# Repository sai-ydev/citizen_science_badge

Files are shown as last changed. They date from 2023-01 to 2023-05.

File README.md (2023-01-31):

# Citizen Science Badge

This repository contains all the hardware files, firmware for the Citizen Science Badge. A detailed write-up of this badge is available from [here](https://www.hackster.io/yamanoorsai/citizen-science-badge-c66165).

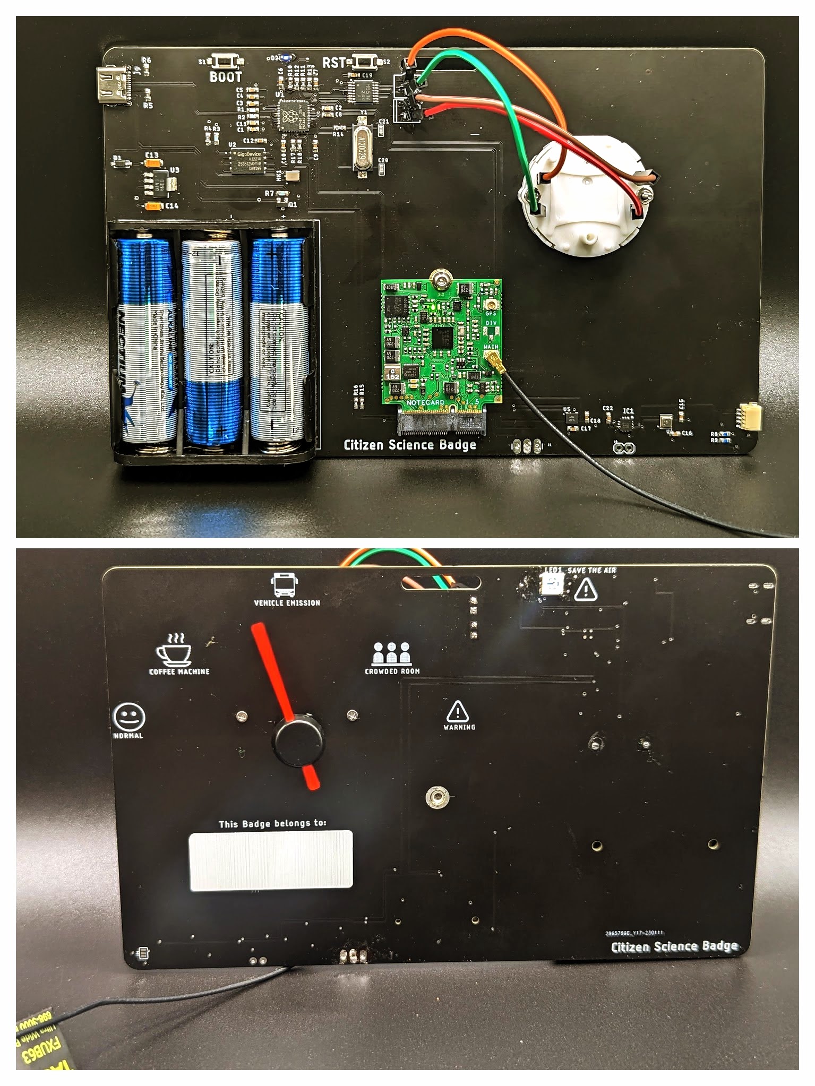
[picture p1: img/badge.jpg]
Citizen Science Badge


The badge consists of the following components:

* Raspberry Pi RP2040 microcontroller with 64MB flash.
* Invensense ICS-41350 MEMS Microphone. The audio captured from the microphone is used to detect sound using Edge Impulse
* Blues Wireless cellular module is used to upload data points to the cloud as well as receive "Save The Air" alerts from the cloud.
* Automotive Gauge Stepper Motor (x27.168) - Used to indicate measured air quality index.
* Bosch BMI270 IMU to detect motion
* DA7280 for haptic feedback
* BME688 air quality sensor to calculate air quality index as well as detect odors
* JST/ Qwiic sensor port for connecting external sensors.
* 3 x AA battery pack
* USB C port for programming.

## Firmware

Currently, the proof of concept has been implemented using Arduino. I plan to implement the code using the RP2040's C SDK. 

I have identified the following items as technical debt for this project.

* Implementing LED behavior for "Spare the Air" alerts
* The PCB design needs to be revised for low power operation
* The code needs to be re-written using the Pico C SDK
* Power profiling the badge

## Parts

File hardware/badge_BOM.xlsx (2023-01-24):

Part | Value | Description | MPN | Remarks
BT1 | BC3AAPC | BC3AAPC | BC3AAPC | Do not Fit
C1, C2, C5, C6, C7, C8, C9, C10, C11, C12, C15, C16, C17, C18, C22 | 0.1uF | CAP CER 0.1UF 25V X7R 0603 | C0603C104K3RAC7867
C3, C4, C19 | 1.0uF | CAP CER 1UF 50V X5R 0603 | GRT188R61H105KE13D
C13 | 68uF | CAP TANT 68UF 20% 6.3V 1206 | T491A686M006AT
C14 | 33uF | CAP TANT 33UF 10% 6.3V 1206 | TAJA336K006RNJ
C20, C21 | 27pf | CAP CER 27PF 50V C0G 0603 | CGA3E2C0G1H270J080AA
D1 | 600 mV @ 200 mA | DIODE SCHOTTKY 30V 350MA SOD123 | SD103BWHE3-TP
D2 | BLUE | LED BLUE 0603 SMD | 5973604507F
IC1 | DA7280-00FVC | LRA/ERM HAPTIC DRIVER WLCSP15 | DA7280-00FVC
J1 |  | CONN_03LONGPADS | DNF
J3 |  | CONN_022.54MM_SCREWTERM | DNF
J4 |  | CONN_022.54MM_SCREWTERM | DNF
J5 |  | CONN HEADER SMD R/A 4POS 1MM | SM04B-SRSS-TB(LF)(SN)
J6 |  | CONN_02 | DNF
J7 | MDT420E01001 | CONN M.2 FMALE 67POS 0.020 GOLD | MDT420E01001
J9 | DX07S016JA1R1500 | CONN RCP USB2.0 TYP C 24P SMD RA | DX07S016JA1R1500
JP1 | JUMPER-SMT_3_NO_SILK | JUMPER-SMT_3_NO_SILK | DNF
LED1 | RGBLED5050 | RGB LED | DNF
MK1 | ICS-41350 | MICROPHONE MEMS DIGITAL PDM OMNI | ICS-41350
Q1 | 2.5A/30V/105mÎ© | MOSFET P-CH 30V 2.5A SOT-23 | DMG2307L-7
R1, R2 | 27 | RES 27 OHM 1% 1/10W 0603 | MCT06030C2709FP500
R3, R7 | 10k | RES 10K OHM 1% 1/10W 0603 | MCT06030C1002FPW00
R4, R11, R12, R13, R14 | 1k | RES 1K OHM 1% 1/8W 0603 | RNCP0603FTD1K00
R5, R6 | 5.1k | RES 5.1K OHM 5% 1/10W 0603 | RMCF0603JT5K10
R8, R9 | 4.7k | RES 4.7K OHM 0.5% 1/10W 0603 | MCT0603MD4701DP500
R10 | 330 | RES 330 OHM 5% 1/10W 0603 | RMCF0603JT330R
R15, R16, R17, R18 | 100 | RES 100 OHMS 0.1% 0.15W 0603 | RQ73C1J100RBTD
S1, S2 | MOMENTARY-SWITCH-SPST-SMD-6.0X3.5MM | TACT 6.0 X 3.5, 4.3 MM H, 130GF, | PTS636 SL43 SMTR LFS
U$1 | TC78H651AFNG | BRUSHED DC MOTOR DRIVER, DUAL-CH | TC78H651AFNG,EL
U1 | RP2040 | RP2040 | SC0914(7) (RP2040)
U2 | W25Q512JVEIM | W25Q512JVEIM | GD25S512MDYIGR
U3 | LP3961EMP-3.3 | IC REG LIN 3.3V 800MA SOT223-5 | LP3961EMP-3.3/NOPB
U4 | BME688 | SENSOR RH PRESSURE TEMP VOC | BME688
U5 | BMI270 | IMU ACCEL/GYRO I2C/SPI 14LGA | BMI270
Y1 | ABLS-12.000MHZ-B4-T | CRYSTAL 12.0000MHZ 18PF SMD | ABLS-12.000MHZ-B4-T

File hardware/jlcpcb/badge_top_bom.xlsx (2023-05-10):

Comment | Designator | Footprint | LCSC Part #
0.1uF | C1 C2 C5 C6 C7 C8 C9 C10 C11 C12 C15 C16 C17 C18 C22 | 603 | C141382
1.0uF | C3 C4 C19 | 603 | C2857982
30V 350mA SOD123 | D1 | SOD123 | C5204743
1k | R11 R12 R13 R14 | 603 | C3017736
2.5A/30V/105mÎ© | Q1 | SOT23-3 | C5182052
4.7k | R8 R9 | 603 | C2904521
5.1k | R5 R6 | 603 | C269716
10k | R3 R7 | 603 | C3017715
27 | R1 R2 | 603 | C176155
27pf | C20 C21 | C0603 | C913896
33uF | C14 | CAPMP3216X180N | C1953983
68uF | C13 | CAPMP3216X180N | C1952895
100 | R15 R16 R17 R18 | 603 | C881316
330 | R10 | 603 | C881395
ABLS-12.000MHZ-B4-T | Y1 | XTAL_ABLS-12.000MHZ-B4-T | ABLS-12.000MHZ-B4-T
BLUE | D2 | LED-0603 | C84266
BME688 | U4 | IC_BME688 | C3664478
BMI270 | U5 | XDCR_BMI270 | C2836813
DA7280-00FVC | IC1 | QFN65P300X300X84-12N | C2155359
DX07S016JA1R1500 | J9 | JAE_DX07S016JA1R1500 | DX07S016JA1R1500
ICS-41350 | MK1 | MIC_ICS-41350 | C2895290
LP3961EMP-3.3 | U3 | SOT150P696X180-5N | C3746120
MDT420E01001NOTECARD | J7 | NOTECARD | MDT420E01001
CONN HEADER SMD R/A 4POS 1MM | J5 |  | C160404
MOMENTARY-SWITCH-SPST-SMD-6.0X3.5MM | S1 S2 | TACTILE_SWITCH_SMD_6.0X3.5MM | C2886923
RP2040 | U1 | QFN40P700X700X90-57N | C2040
TC78H651AFNG | U$1 | P-TSSOP16-0505-0.65-001 | TC78H651AFNG
W25Q512JVEIM | U2 | SON127P600X800X80-9N | C2886434

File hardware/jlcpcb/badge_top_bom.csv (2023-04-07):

Comment | Designator | Footprint | LCSC Part #
0.1uF | D1 J5 C1 C2 C5 C6 C7 C8 C9 C10 C11 C12 C15 C16 C17 C18 C22 | 0603
1.0uF | C3 C4 C19 | 0603
1k | R11 R12 R13 R14 | 0603
2.5A/30V/105mΩ | Q1 | SOT23-3
4.7k | R8 R9 | 0603
5.1k | R5 R6 | 0603
10k | R3 R7 | 0603
27 | R1 R2 | 0603
27pf | C20 C21 | C0603
33uF | C14 | CAPMP3216X180N
68uF | C13 | CAPMP3216X180N
100 | R15 R16 R17 R18 | 0603
330 | R10 | 0603
ABLS-12.000MHZ-B4-T | Y1 | XTAL_ABLS-12.000MHZ-B4-T
BLUE | D2 | LED-0603
BME688 | U4 | IC_BME688
BMI270 | U5 | XDCR_BMI270
DA7280-00FVC | IC1 | QFN65P300X300X84-12N
DX07S016JA1R1500 | J9 | JAE_DX07S016JA1R1500
ICS-41350 | MK1 | MIC_ICS-41350
LP3961EMP-3.3 | U3 | SOT150P696X180-5N
MDT420E01001NOTECARD | J7 | NOTECARD
MOMENTARY-SWITCH-SPST-SMD-6.0X3.5MM | S1 S2 | TACTILE_SWITCH_SMD_6.0X3.5MM
RP2040 | U1 | QFN40P700X700X90-57N
TC78H651AFNG | U$1 | P-TSSOP16-0505-0.65-001
W25Q512JVEIM | U2 | SON127P600X800X80-9N

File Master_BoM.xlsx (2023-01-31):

Item | Manufacturer / Vendor | Price | Remarks
Fully Assembled PCB | PCBWay | 103.6 | PCB BoM in Github contains more detailed information
Automotive Stepper | Adafruit | 9.95
3 x AA Batteries | Amazon | 3
Notecard cellular module | Blues Wireless | 64.9
Cellular module antenna | Taoglas | 11.91
 | Total | 193.36

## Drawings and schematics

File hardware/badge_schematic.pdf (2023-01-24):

A

A

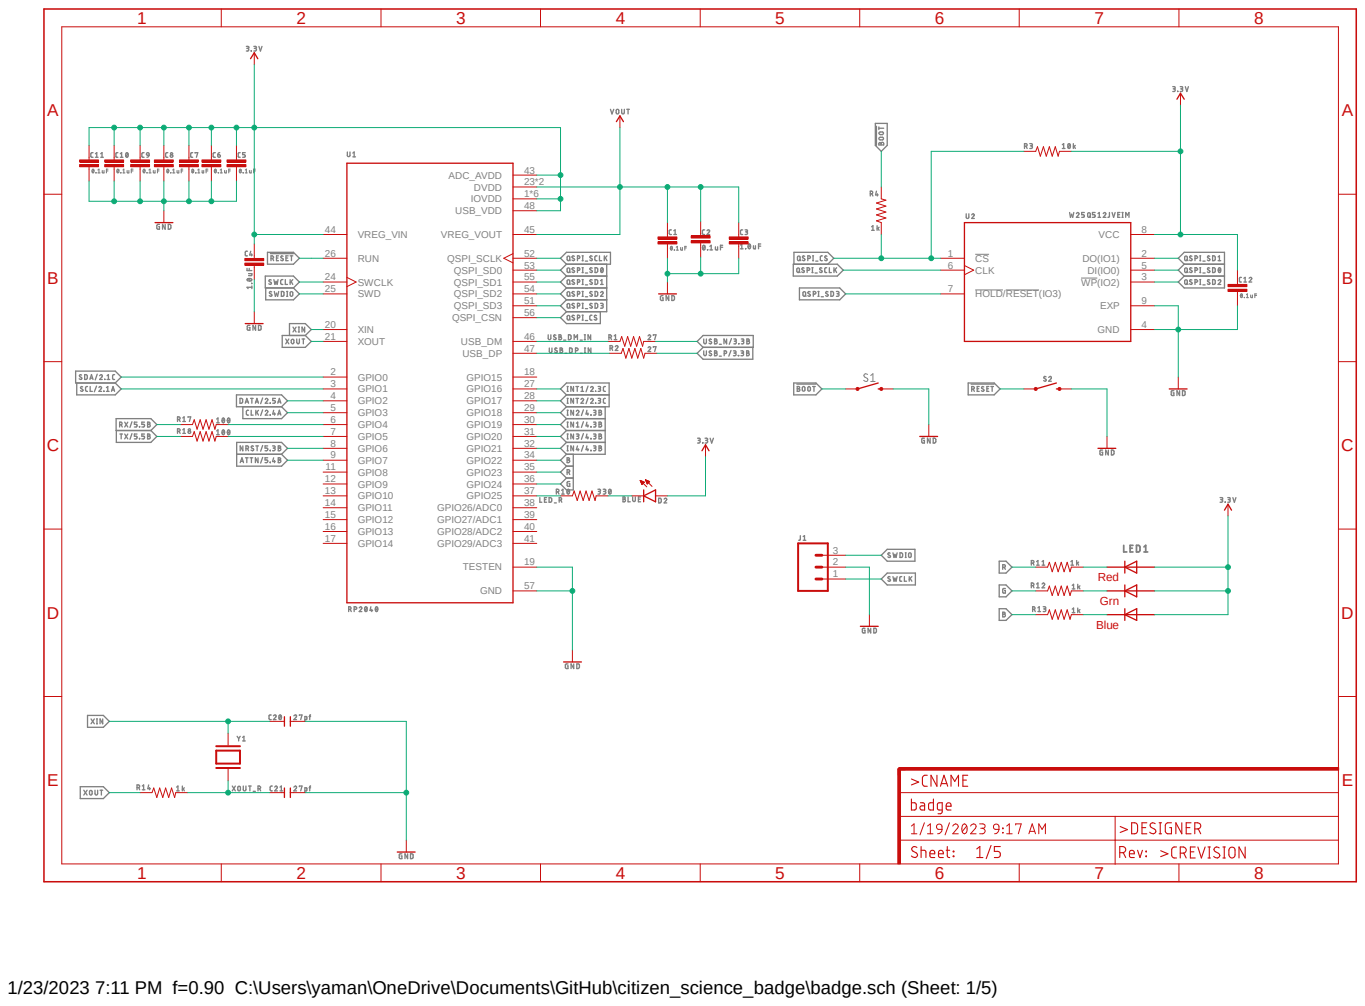
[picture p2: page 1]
GPIO0 2; GPIO1 3; GPIO2 4; GPIO3 5; GPIO4 6; GPIO5 7; GPIO6 8; GPIO7 9; GPIO8 11; GPIO9 12; GPIO10 13; GPIO11 14; GPIO12 15; GPIO13 16; GPIO14 17; GPIO15; 18 GPIO16; 27 GPIO17; 28 GPIO18; 29 GPIO19; 30 GPIO20; 31 GPIO21; 32 GPIO22; 34 GPIO23; 35 GPIO24; 36 GPIO25; 37 GPIO26/ADC0; 38 GPIO27/ADC1; 39 GPIO28/ADC2; 40 GPIO29/ADC3; 41 QSPI_SD3; 51 QSPI_SCLK; 52 QSPI_SD0; 53 QSPI_SD2; 54 QSPI_SD1; 55 QSPI_CSN; 56 XIN 20; XOUT 21; SWCLK 24; SWD 25; RUN 26; TESTEN; 19 USB_DP; 47 USB_DM; 46 VREG_VOUT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

1/23/2023 7:11 PM f=0.90 C:\Users\yaman\OneDrive\Documents\GitHub\citizen_science_badge\badge.sch (Sheet: 1/5)

A

A

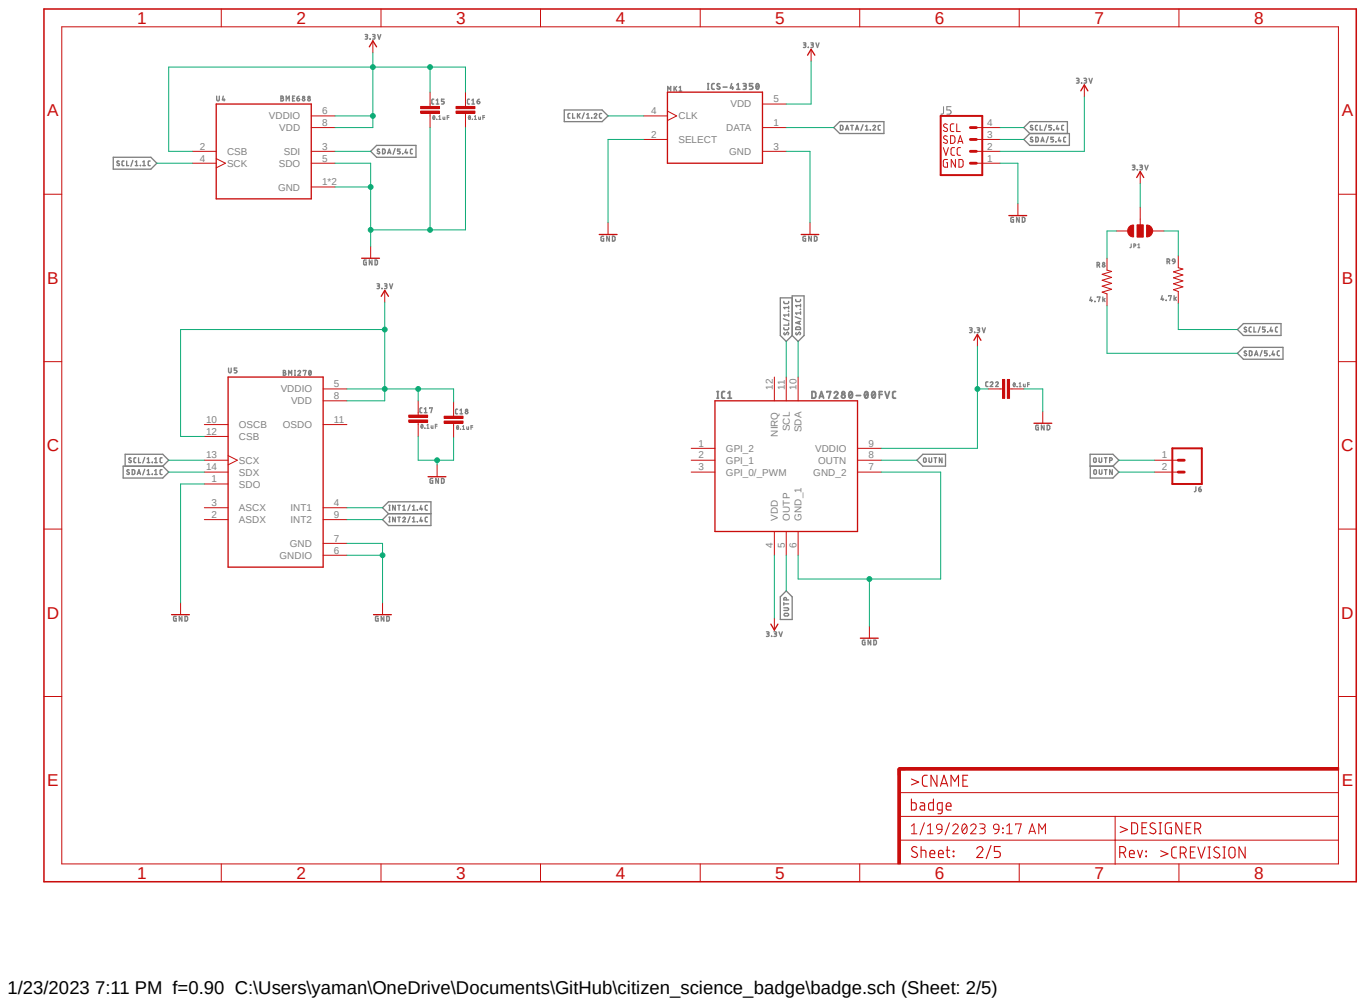
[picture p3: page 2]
CSB 2; SDI; 3 SCK 4; SDO; 5 VDDIO; 6 GND; 1*2 VDD; SDO 1; ASDX 2; ASCX 3; INT1; 4 VDDIO; 5 GNDIO; 7 VDD; INT2; 9 OSDO; 11 CSB 12; OSCB 10; SCX 13; SDX 14; VDD; 5 DATA; 1 GND; 3 CLK 4; SELECT 2; 4 GPI_2 1; GPI_1 2; GPI_0/_PWM 3; 4 OUTP; 5 GND_1

6 VDDIO 9 OUTN 8 GND_2 7 NIRQ 12 SCL 11 SDA 10

1/23/2023 7:11 PM f=0.90 C:\Users\yaman\OneDrive\Documents\GitHub\citizen_science_badge\badge.sch (Sheet: 2/5)

A

1 | 2 | 3 | 4 | 5 | 6 | 7 | 8

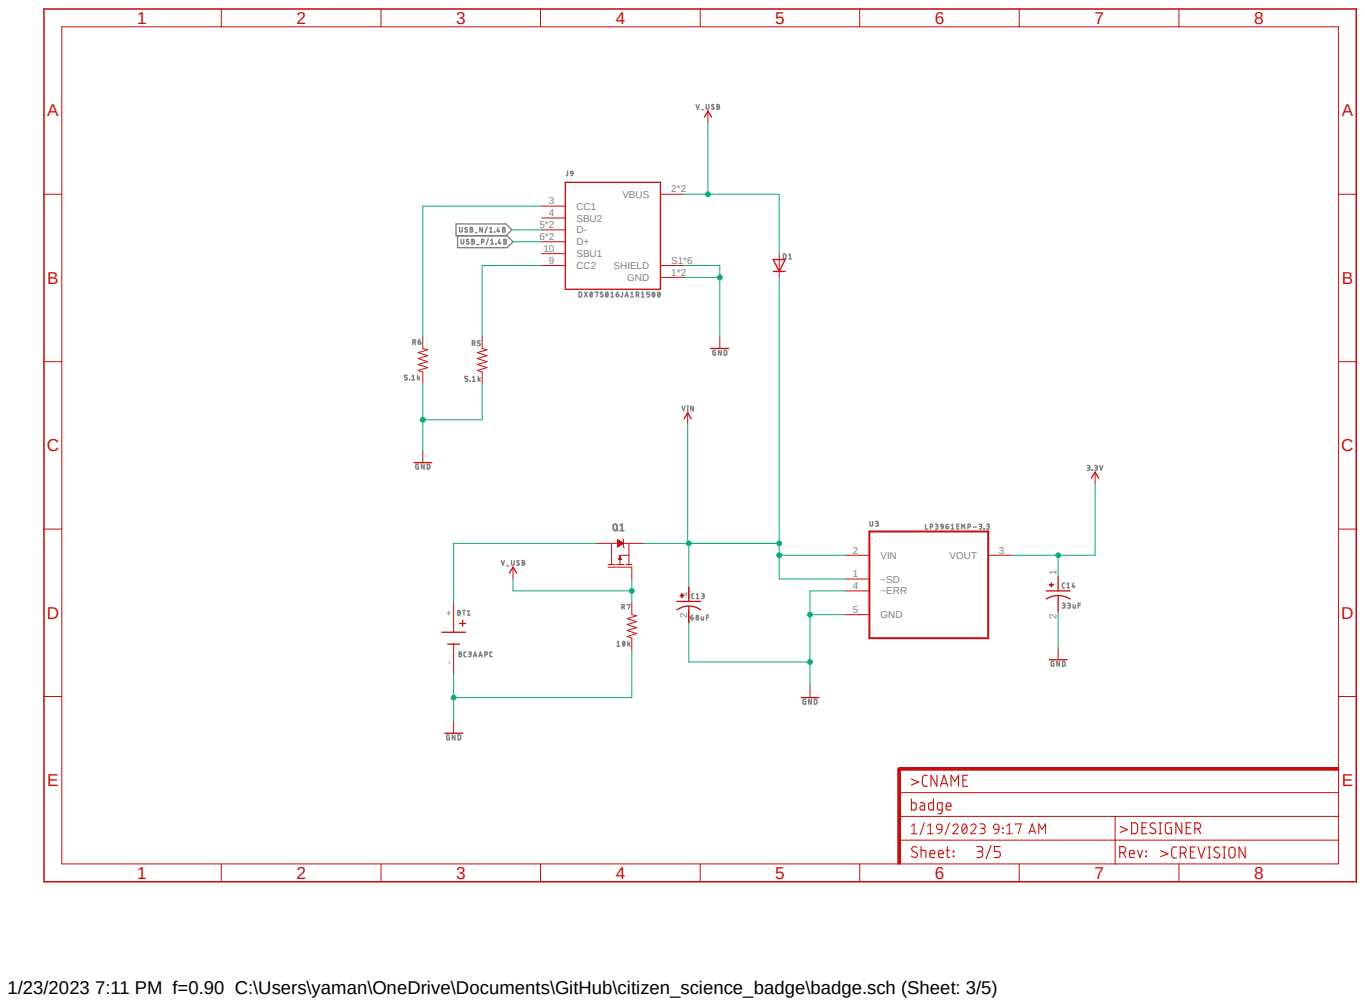
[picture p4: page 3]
VIN 2; ~ERR 4; GND 5; VOUT; GND; 1*2 VBUS; SBU2 4; SBU1 10; SHIELD

1/23/2023 7:11 PM f=0.90 C:\Users\yaman\OneDrive\Documents\GitHub\citizen_science_badge\badge.sch (Sheet: 3/5)

A

A

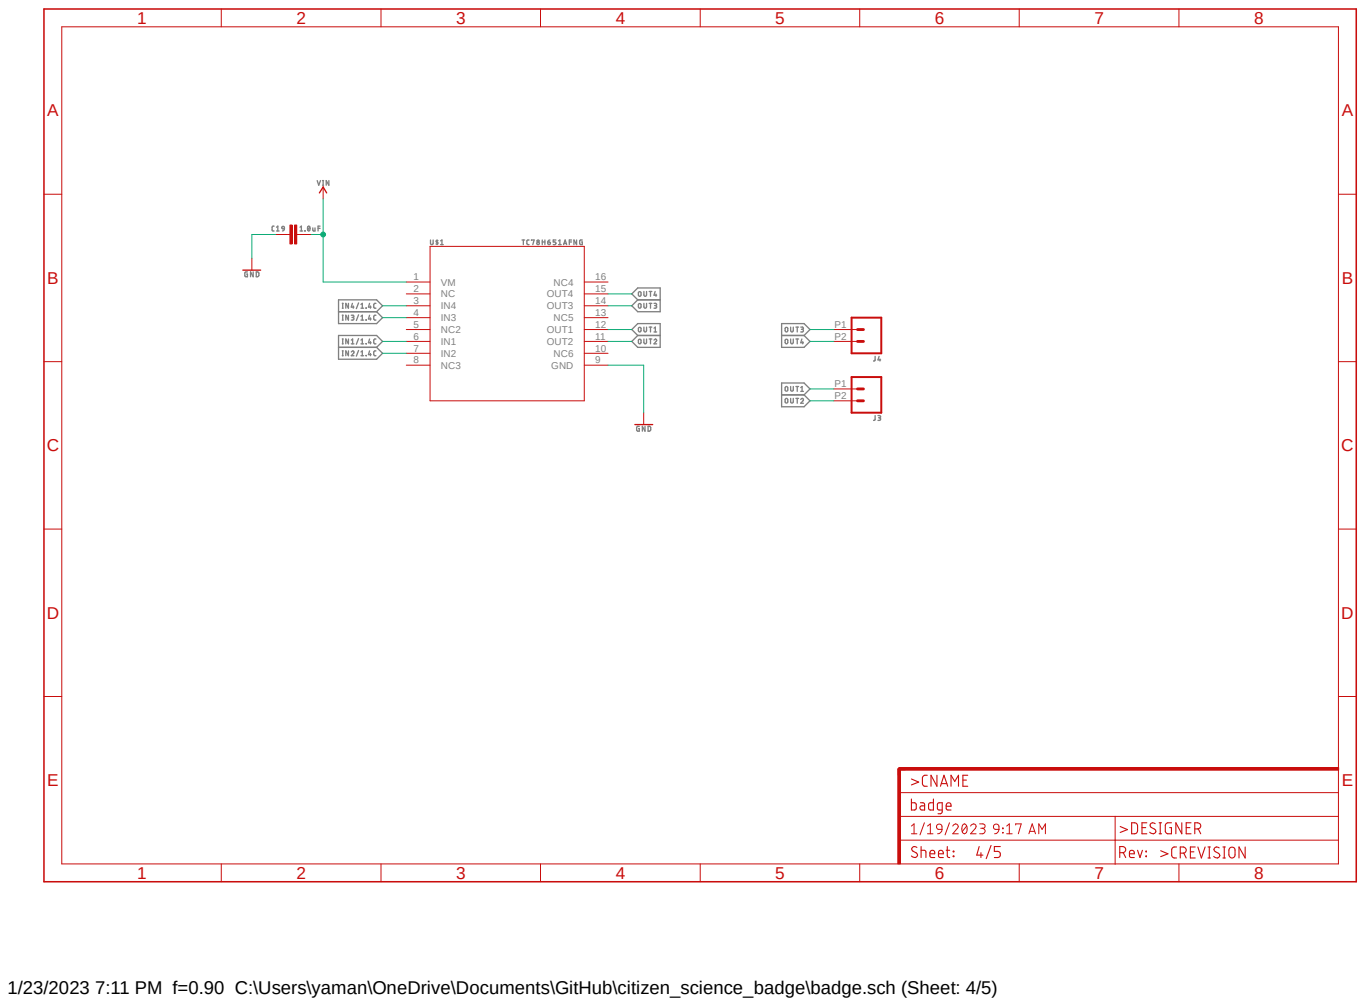
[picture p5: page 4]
GND; 10 OUT2; 11 OUT1; 13 OUT3; 14 OUT4

1/23/2023 7:11 PM f=0.90 C:\Users\yaman\OneDrive\Documents\GitHub\citizen_science_badge\badge.sch (Sheet: 4/5)

A

A

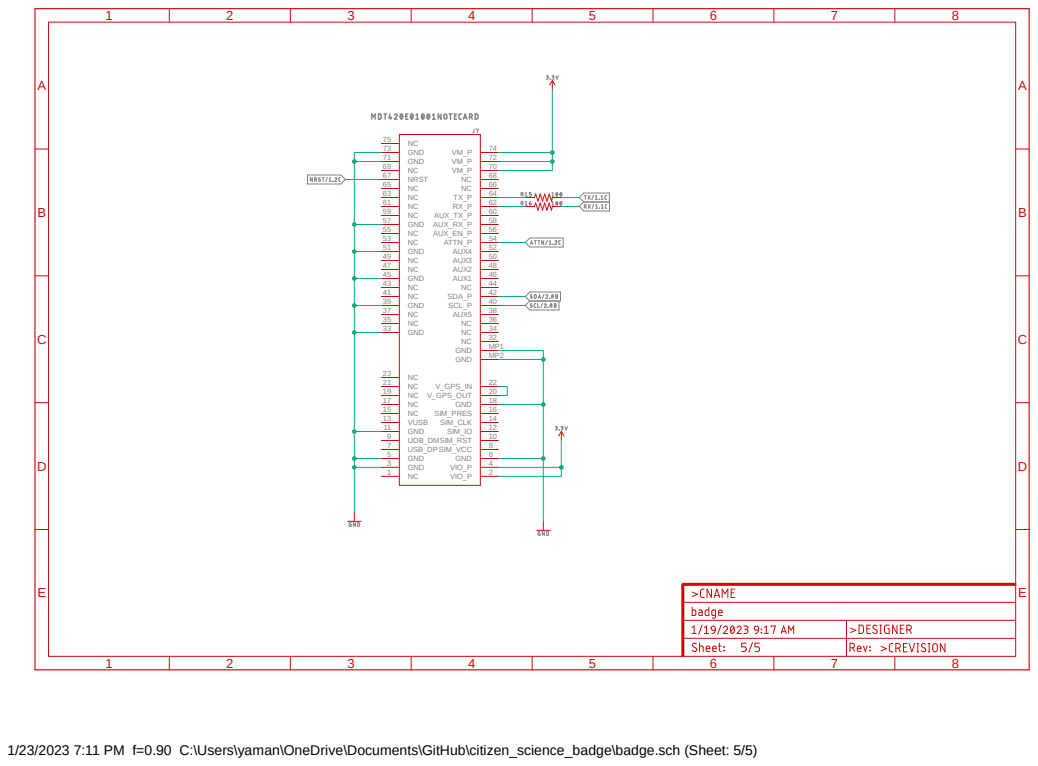
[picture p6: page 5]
VIO_P; 2 GND 3; 4 GND 5; GND; 6 USB_DP 7; SIM_VCC; 8 UDB_DM 9; SIM_RST; 10 GND 11; SIM_IO; 12 VUSB 13; SIM_CLK; SIM_PRES; V_GPS_OUT; V_GPS_IN; 32 GND 33; AUX5; 38 GND 39; SCL_P; SDA_P; 44 GND 45; AUX1; AUX2; AUX3; 50 GND 51; AUX4; ATTN_P; AUX_EN_P; 56 GND 57; AUX_RX_P; AUX_TX_P; 66 NRST 67; 70 GND 71; 72 GND 73; MP1 GND

1/23/2023 7:11 PM f=0.90 C:\Users\yaman\OneDrive\Documents\GitHub\citizen_science_badge\badge.sch (Sheet: 5/5)

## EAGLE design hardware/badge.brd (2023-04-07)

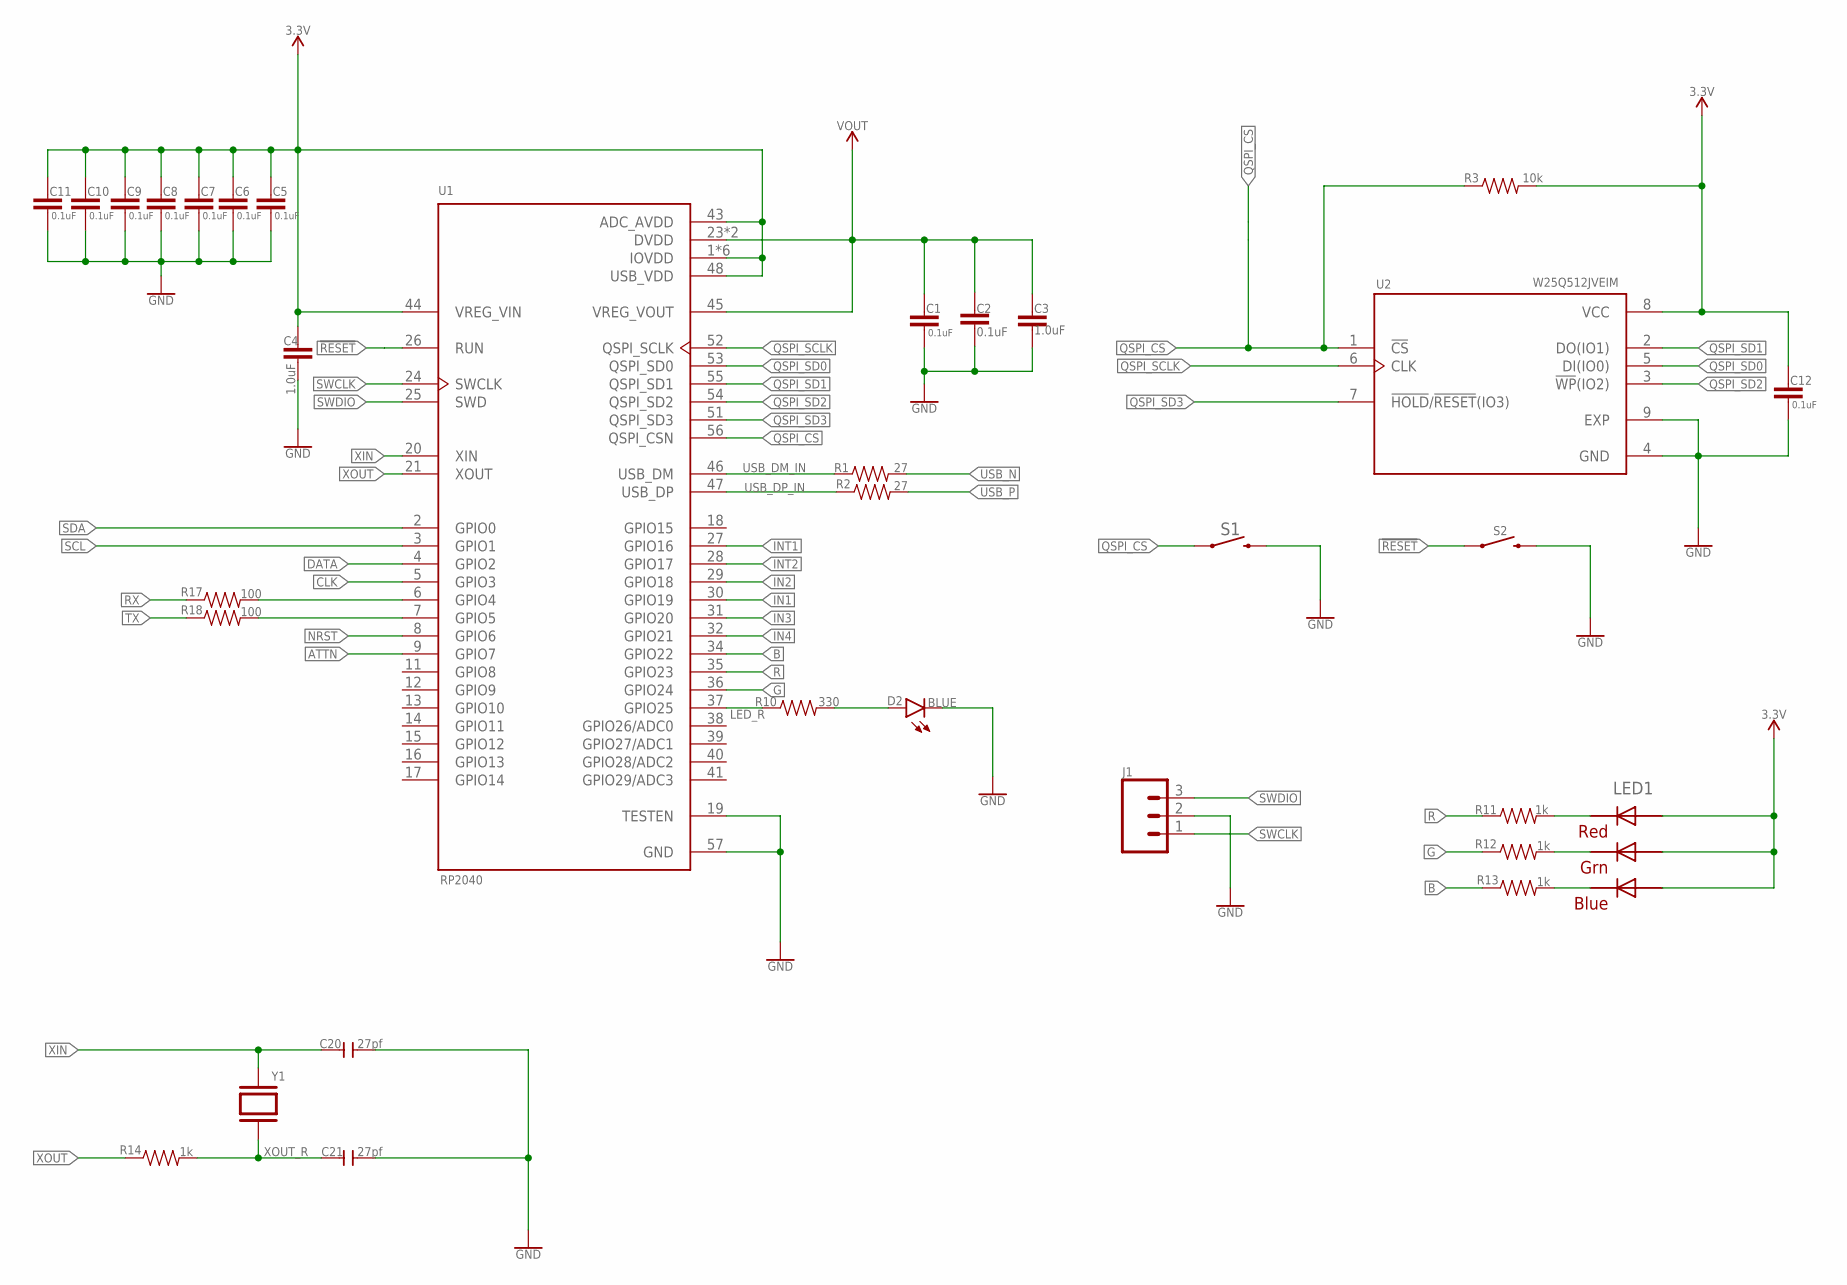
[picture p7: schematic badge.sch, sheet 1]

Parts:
C1, C2, C5, C6, C7, C8, C9, C10, C11, C12: 0.1uF; 0603
C3, C4: 1.0uF; 0603
C20, C21: 27pf; C0603
D2: BLUE; LED-0603
J1: CONN_03LONGPADS; 1X03_LONGPADS
LED1: RGBLED5050
R1, R2: 27; 0603
R3: 10k; 0603
R10: 330; 0603
R11, R12, R13, R14: 1k; 0603
R17, R18: 100; 0603
S1, S2: MOMENTARY-SWITCH-SPST-SMD-6.0X3.5MM; TACTILE_SWITCH_SMD_6.0X3.5MM
U1: RP2040; QFN40P700X700X90-57N
U2: W25Q512JVEIM; SON127P600X800X80-9N
Y1: ABLS-12.000MHZ-B4-T; XTAL_ABLS-12.000MHZ-B4-T

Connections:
3.3V: C4.1, C5.1, C6.1, C7.1, C8.1, C9.1, C10.1, C11.1, C12.1, LED1.1 (GREEN_A), LED1.2 (RED_A), LED1.3 (BLUE_A), R3.2, U1.1 (IOVDD), U1.10 (IOVDD), U1.22 (IOVDD), U1.33 (IOVDD), U1.42 (IOVDD), U1.43 (ADC_AVDD), U1.44 (VREG_VIN), U1.48 (USB_VDD), U1.49 (IOVDD), U2.8 (VCC); also elsewhere on the board
!RESET: S2.1, U1.26 (RUN)
ATTN: U1.9 (GPIO7); also elsewhere on the board
B: R13.1, U1.34 (GPIO22)
CLK: U1.5 (GPIO3); also elsewhere on the board
DATA: U1.4 (GPIO2); also elsewhere on the board
G: R12.1, U1.36 (GPIO24)
GND: C1.2, C2.2, C3.2, C4.2, C5.2, C6.2, C7.2, C8.2, C9.2, C10.2, C11.2, C12.2, C20.2, C21.2, D2.C, J1.2, S1.2, S2.2, U1.19 (TESTEN), U1.57 (GND), U2.4 (GND), U2.9 (EXP); also elsewhere on the board
IN1: U1.30 (GPIO19); also elsewhere on the board
IN2: U1.29 (GPIO18); also elsewhere on the board
IN3: U1.31 (GPIO20); also elsewhere on the board
IN4: U1.32 (GPIO21); also elsewhere on the board
INT1: U1.27 (GPIO16); also elsewhere on the board
INT2: U1.28 (GPIO17); also elsewhere on the board
LED_R: R10.1, U1.37 (GPIO25)
unnamed: D2.A, R10.2
unnamed: LED1.5 (RED_C), R11.2
unnamed: LED1.6 (GREEN_C), R12.2
unnamed: LED1.4 (BLUE_C), R13.2
unnamed: R17.2, U1.6 (GPIO4)
unnamed: R18.2, U1.7 (GPIO5)
NRST: U1.8 (GPIO6); also elsewhere on the board
QSPI_CS: R3.1, S1.1, U1.56 (QSPI_CSN), U2.1 (!CS)
QSPI_SCLK: U1.52 (QSPI_SCLK), U2.6 (CLK)
QSPI_SD0: U1.53 (QSPI_SD0), U2.5 (DI(IO0))
QSPI_SD1: U1.55 (QSPI_SD1), U2.2 (DO(IO1))
QSPI_SD2: U1.54 (QSPI_SD2), U2.3 (!WP!(IO2))
QSPI_SD3: U1.51 (QSPI_SD3), U2.7 (!HOLD!/!RESET!(IO3))
R: R11.1, U1.35 (GPIO23)
RX: R17.1; also elsewhere on the board
SCL: U1.3 (GPIO1); also elsewhere on the board
SDA: U1.2 (GPIO0); also elsewhere on the board
SWCLK: J1.1, U1.24 (SWCLK)
SWDIO: J1.3, U1.25 (SWD)
TX: R18.1; also elsewhere on the board
USB_DM_IN: R1.1, U1.46 (USB_DM)
USB_DP_IN: R2.1, U1.47 (USB_DP)
USB_N: R1.2; also elsewhere on the board
USB_P: R2.2; also elsewhere on the board
VOUT: C1.1, C2.1, C3.1, U1.23 (DVDD), U1.45 (VREG_VOUT), U1.50 (DVDD)
XIN: C20.1, U1.20 (XIN), Y1.2
XOUT: R14.1, U1.21 (XOUT)
XOUT_R: C21.1, R14.2, Y1.1

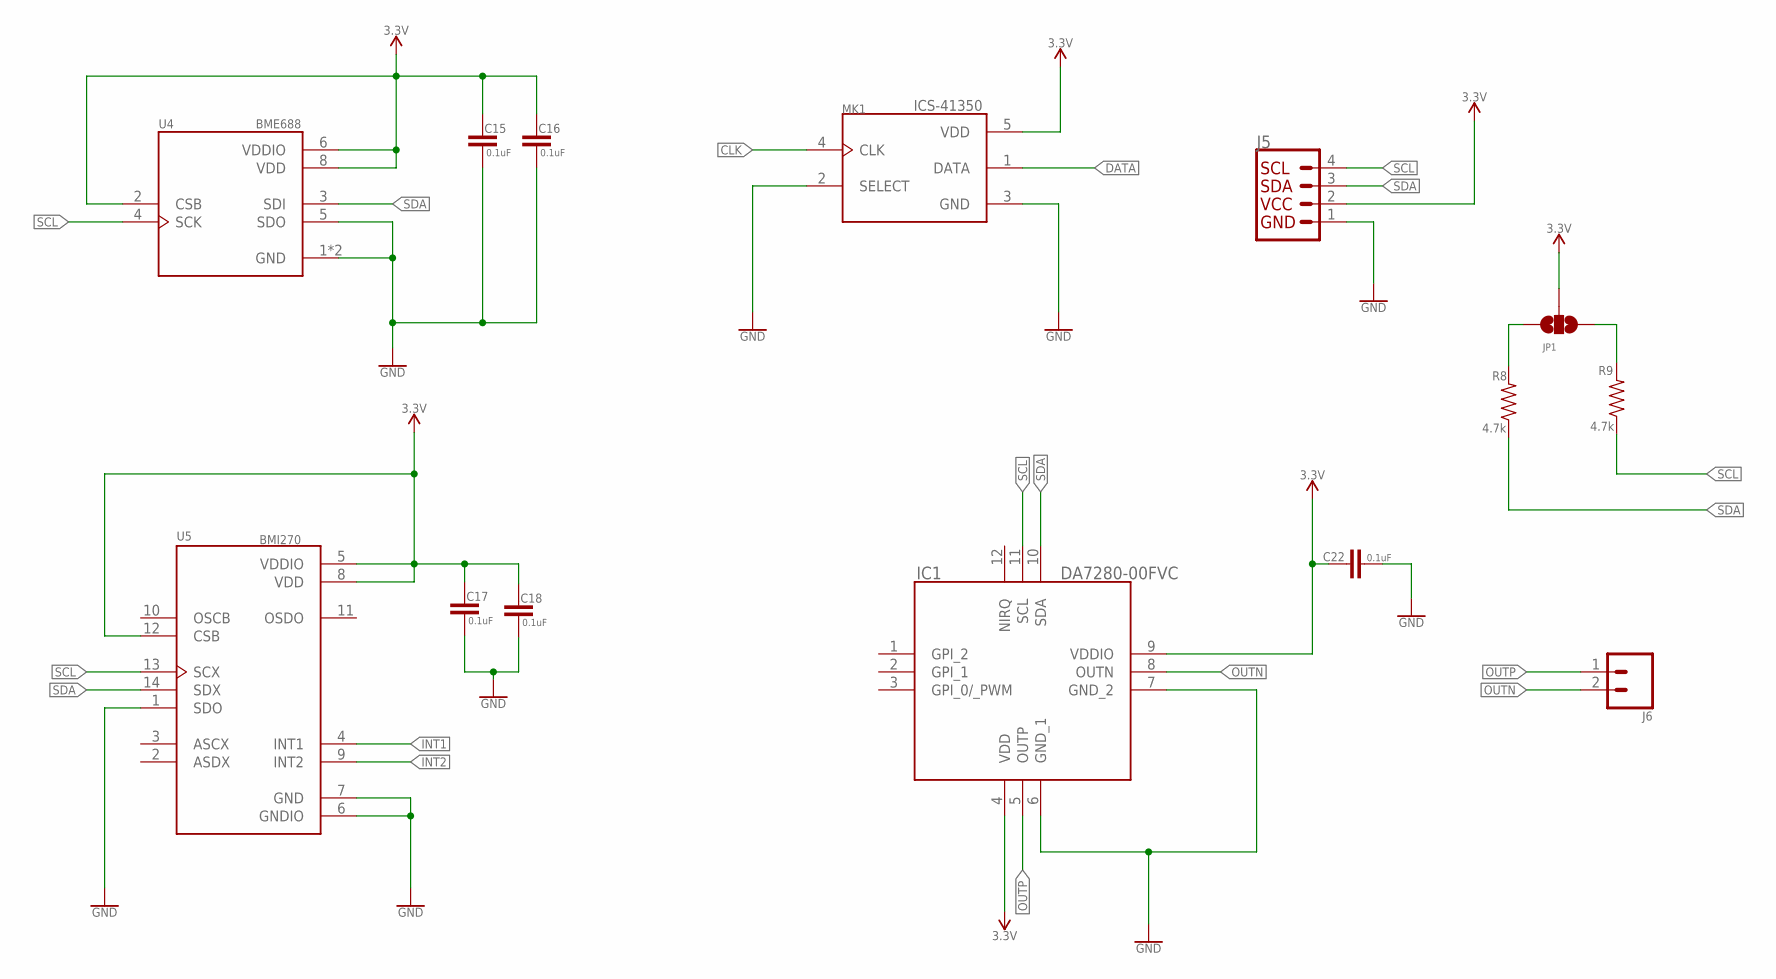
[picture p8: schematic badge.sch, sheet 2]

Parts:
C15, C16, C17, C18, C22: 0.1uF; 0603
IC1: DA7280-00FVC; QFN65P300X300X84-12N
J5: QWIIC_CONNECTORJS-1MM; 1X04_1MM_RA
J6: CONN_02; 1X02
JP1: JUMPER-SMT_3_NO_SILK; SMT-JUMPER_3_NO_SILK
MK1: ICS-41350; MIC_ICS-41350
R8, R9: 4.7k; 0603
U4: BME688; IC_BME688
U5: BMI270; XDCR_BMI270

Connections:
3.3V: C15.1, C16.1, C17.1, C18.1, C22.1, IC1.4 (VDD), IC1.9 (VDDIO), J5.2 (VCC), JP1.2, MK1.5 (VDD), U4.2 (CSB), U4.6 (VDDIO), U4.8 (VDD), U5.5 (VDDIO), U5.8 (VDD), U5.12 (CSB); also elsewhere on the board
CLK: MK1.4 (CLK); also elsewhere on the board
DATA: MK1.1 (DATA); also elsewhere on the board
GND: C15.2, C16.2, C17.2, C18.2, C22.2, IC1.6 (GND_1), IC1.7 (GND_2), J5.1 (GND), MK1.2 (SELECT), MK1.3 (GND), U4.1 (GND), U4.5 (SDO), U4.7 (GND), U5.1 (SDO), U5.6 (GNDIO), U5.7 (GND); also elsewhere on the board
INT1: U5.4 (INT1); also elsewhere on the board
INT2: U5.9 (INT2); also elsewhere on the board
unnamed: JP1.3, R8.2
unnamed: JP1.1, R9.2
OUTN: IC1.8 (OUTN), J6.2
OUTP: IC1.5 (OUTP), J6.1
SCL: IC1.11 (SCL), J5.4 (SCL), R9.1, U4.4 (SCK), U5.13 (SCX); also elsewhere on the board
SDA: IC1.10 (SDA), J5.3 (SDA), R8.1, U4.3 (SDI), U5.14 (SDX); also elsewhere on the board

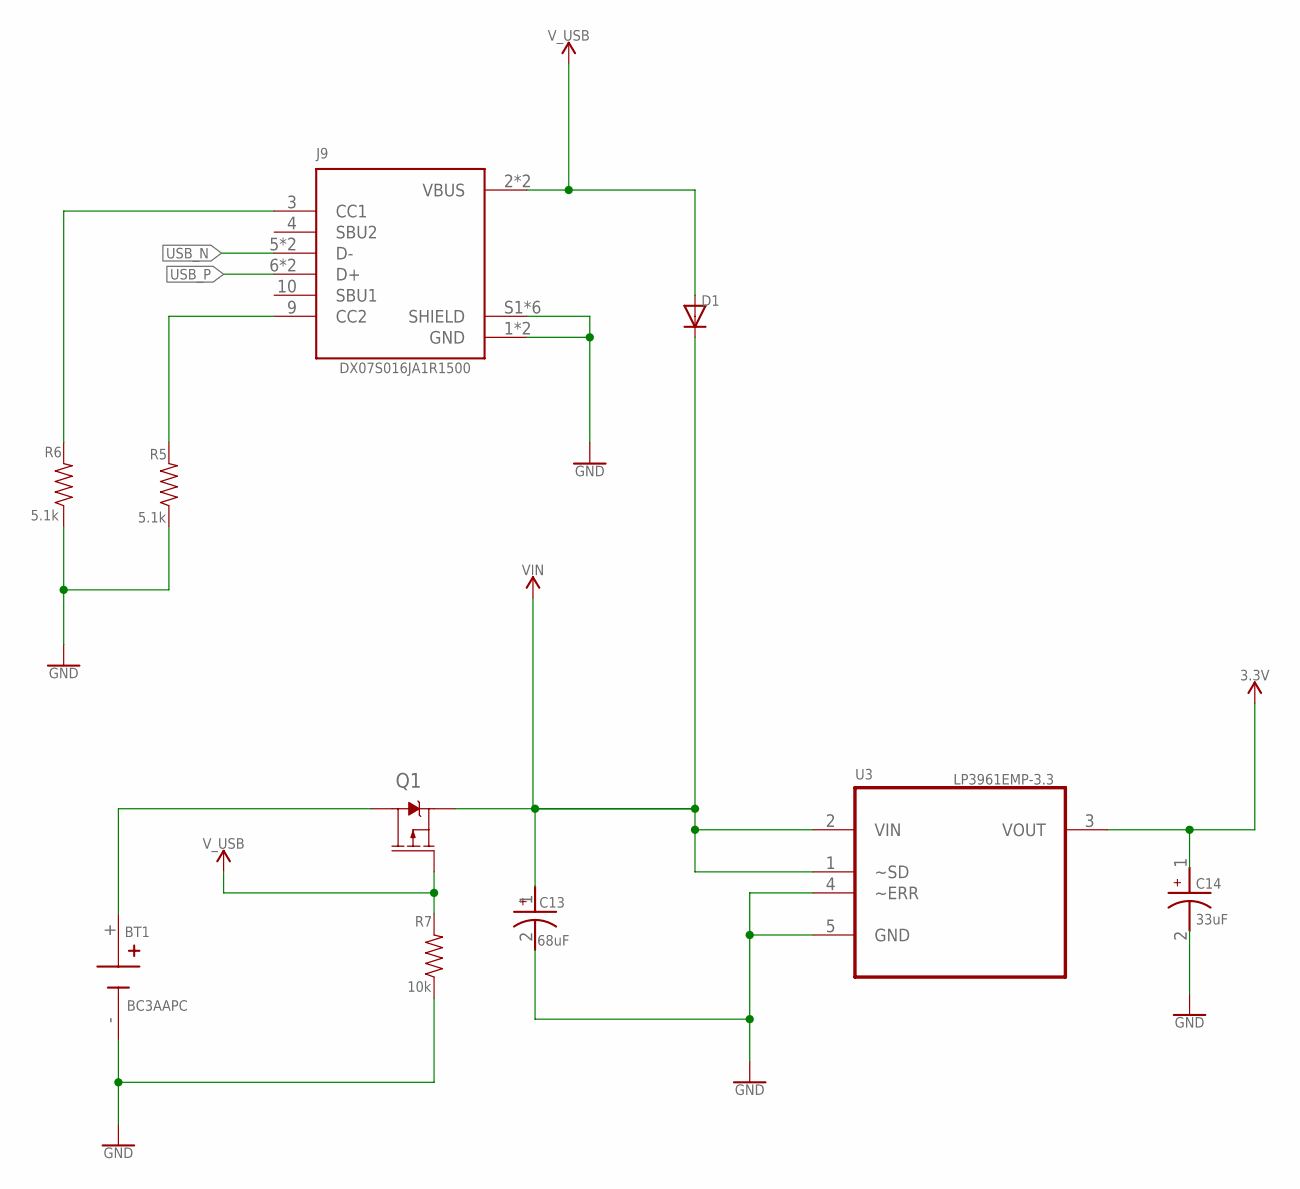
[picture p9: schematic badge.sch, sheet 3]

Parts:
BT1: BC3AAPC; BAT_BC3AAPC
C13: 68uF; CAPMP3216X180N
C14: 33uF; CAPMP3216X180N
D1: DIODESOD-123; SOD-123
J9: DX07S016JA1R1500; JAE_DX07S016JA1R1500
Q1: 2.5A/30V/105mΩ; SOT23-3
R5, R6: 5.1k; 0603
R7: 10k; 0603
U3: LP3961EMP-3.3; SOT150P696X180-5N

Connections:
3.3V: C14.1, U3.3 (VOUT); also elsewhere on the board
GND: BT1.-, C13.2, C14.2, J9.1 (GND), J9.12 (GND), J9.S1 (SHIELD), J9.S2 (SHIELD), J9.S3 (SHIELD), J9.S4 (SHIELD), J9.S5 (SHIELD), J9.S6 (SHIELD), R5.1, R6.1, R7.1, U3.4 (~ERR), U3.5 (GND); also elsewhere on the board
unnamed: BT1.+, Q1.3 (D)
unnamed: J9.3 (CC1), R6.2
unnamed: J9.9 (CC2), R5.2
USB_N: J9.5 (D-), J9.8 (D-); also elsewhere on the board
USB_P: J9.6 (D+), J9.7 (D+); also elsewhere on the board
VIN: C13.1, D1.C, Q1.2 (S), U3.1 (~SD), U3.2 (VIN); also elsewhere on the board
V_USB: D1.A, J9.2 (VBUS), J9.11 (VBUS), Q1.1 (G), R7.2

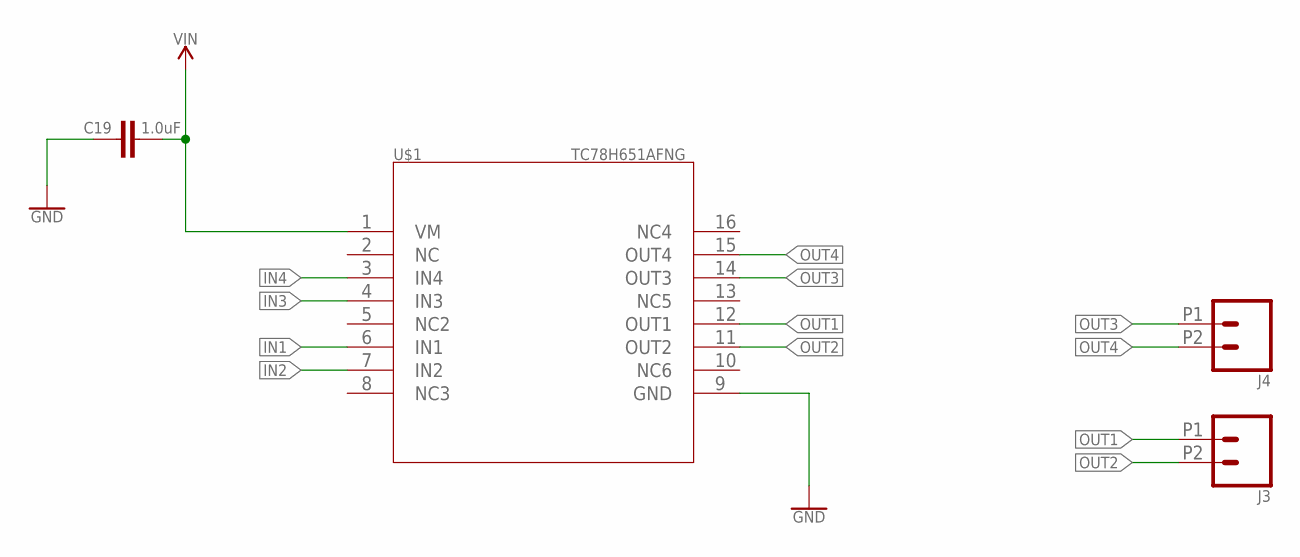
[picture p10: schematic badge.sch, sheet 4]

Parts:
C19: 1.0uF; 0603
J3, J4: CONN_022.54MM_SCREWTERM; 1X02_2.54_SCREWTERM
U$1: TC78H651AFNG; P-TSSOP16-0505-0.65-001

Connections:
GND: C19.1, U$1.9 (GND); also elsewhere on the board
IN1: U$1.6 (IN1); also elsewhere on the board
IN2: U$1.7 (IN2); also elsewhere on the board
IN3: U$1.4 (IN3); also elsewhere on the board
IN4: U$1.3 (IN4); also elsewhere on the board
OUT1: J3.P1 (1), U$1.12 (OUT1)
OUT2: J3.P2 (2), U$1.11 (OUT2)
OUT3: J4.P1 (1), U$1.14 (OUT3)
OUT4: J4.P2 (2), U$1.15 (OUT4)
VIN: C19.2, U$1.1 (VM); also elsewhere on the board

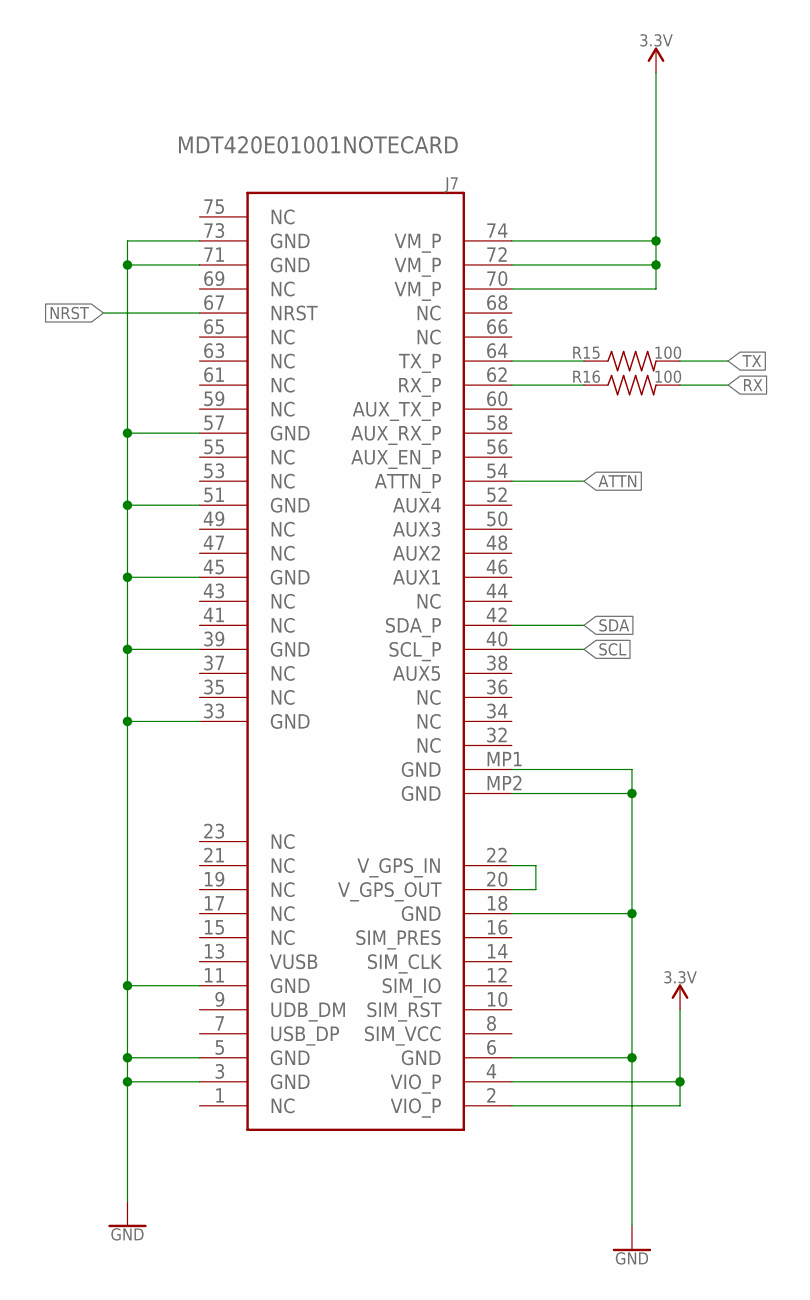
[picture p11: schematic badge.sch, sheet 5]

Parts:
J7: MDT420E01001NOTECARD; NOTECARD
R15, R16: 100; 0603

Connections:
3.3V: J7.2 (VIO_P), J7.4 (VIO_P), J7.70 (VM_P), J7.72 (VM_P), J7.74 (VM_P); also elsewhere on the board
ATTN: J7.54 (ATTN_P); also elsewhere on the board
GND: J7.3 (GND), J7.5 (GND), J7.6 (GND), J7.11 (GND), J7.18 (GND), J7.33 (GND), J7.39 (GND), J7.45 (GND), J7.51 (GND), J7.57 (GND), J7.71 (GND), J7.73 (GND), J7.MP1 (GND), J7.MP2 (GND); also elsewhere on the board
unnamed: J7.64 (TX_P), R15.1
unnamed: J7.62 (RX_P), R16.1
unnamed: J7.20 (V_GPS_OUT), J7.22 (V_GPS_IN)
NRST: J7.67 (NRST); also elsewhere on the board
RX: R16.2; also elsewhere on the board
SCL: J7.40 (SCL_P); also elsewhere on the board
SDA: J7.42 (SDA_P); also elsewhere on the board
TX: R15.2; also elsewhere on the board

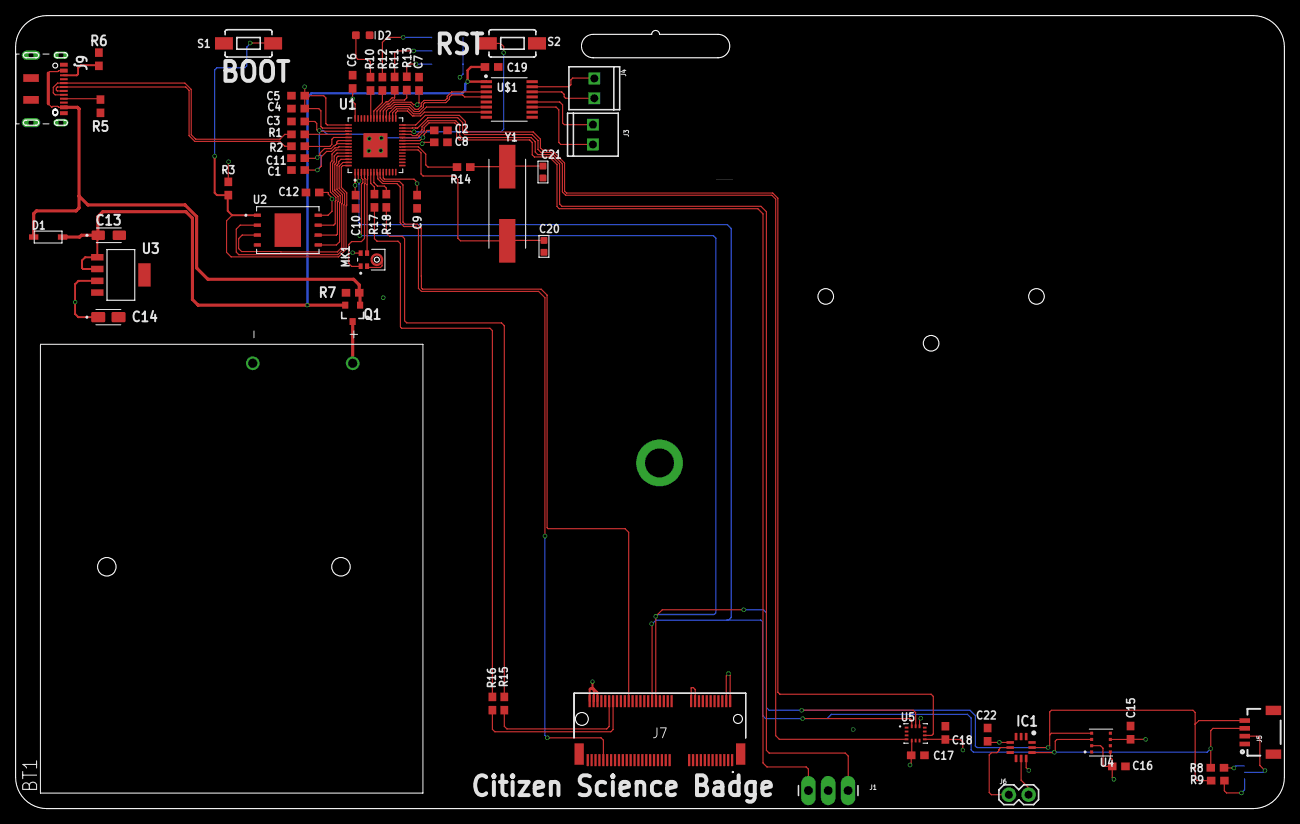
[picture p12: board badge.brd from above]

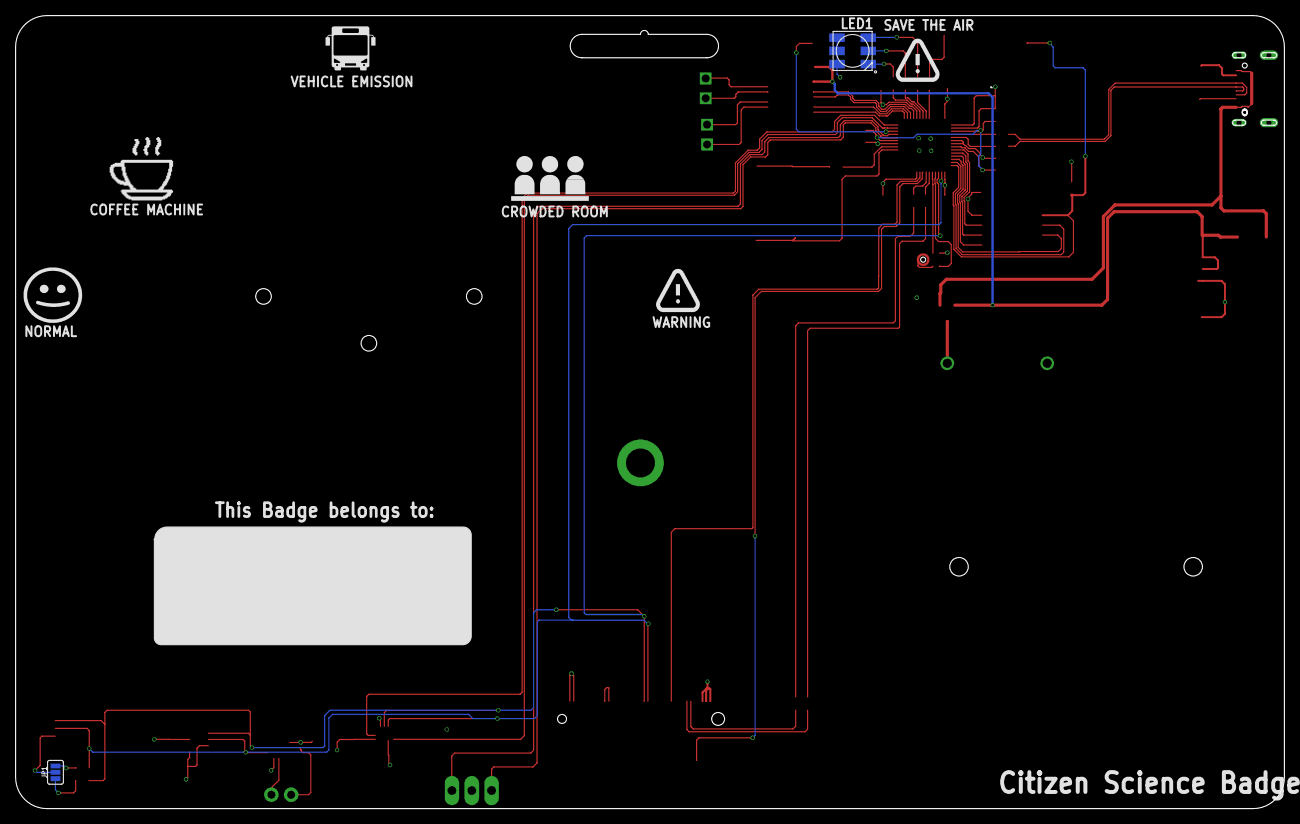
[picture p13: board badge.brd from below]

Board: 4 copper layers, 162.6 x 101.6 mm, 63 parts (2 on the bottom side), 59 nets.

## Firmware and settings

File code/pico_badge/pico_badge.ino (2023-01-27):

/* Edge Impulse ingestion SDK
   Copyright (c) 2022 EdgeImpulse Inc.

   Licensed under the Apache License, Version 2.0 (the "License");
   you may not use this file except in compliance with the License.
   You may obtain a copy of the License at
   http://www.apache.org/licenses/LICENSE-2.0

   Unless required by applicable law or agreed to in writing, software
   distributed under the License is distributed on an "AS IS" BASIS,
   WITHOUT WARRANTIES OR CONDITIONS OF ANY KIND, either express or implied.
   See the License for the specific language governing permissions and
   limitations under the License.

*/

// If your target is limited in memory remove this macro to save 10K RAM
#define EIDSP_QUANTIZE_FILTERBANK   0

/*
 ** NOTE: If you run into TFLite arena allocation issue.
 **
 ** This may be due to may dynamic memory fragmentation.
 ** Try defining "-DEI_CLASSIFIER_ALLOCATION_STATIC" in boards.local.txt (create
 ** if it doesn't exist) and copy this file to
 ** `<ARDUINO_CORE_INSTALL_PATH>/arduino/hardware/<mbed_core>/<core_version>/`.
 **
 ** See
 ** (https://support.arduino.cc/hc/en-us/articles/360012076960-Where-are-the-installed-cores-located-)
 ** to find where Arduino installs cores on your machine.
 **
 ** If the problem persists then there's not enough memory for this model and application.
*/

/* Includes ---------------------------------------------------------------- */
#include <Audio_Pico_Badge_inferencing.h>
#include <Stepper.h>
#include <PDM.h>
#include <bsec2.h>
#include <Notecard.h>

/* Macros used */
#define PANIC_LED   LED_BUILTIN
#define ERROR_DUR   1000

#define productUID ""
Notecard notecard;

/** Audio buffers, pointers and selectors */
typedef struct {
  int16_t *buffer;
  uint8_t buf_ready;
  uint32_t buf_count;
  uint32_t n_samples;
} inference_t;

static inference_t inference;
static signed short sampleBuffer[2048];
static bool debug_nn = false; // Set this to true to see e.g. features generated from the raw signal
static volatile bool record_ready = false;
long current_time = 0;
Stepper stepper(630, 19, 18, 20, 21);

/* Helper functions declarations */
/**
   @brief : This function toggles the led when a fault was detected
*/
void errLeds(void);

/**
   @brief : This function checks the BSEC status, prints the respective error code. Halts in case of error
   @param[in] bsec  : Bsec2 class object
*/
void checkBsecStatus(Bsec2 bsec);

/**
   @brief : This function is called by the BSEC library when a new output is available
   @param[in] input     : BME68X sensor data before processing
   @param[in] outputs   : Processed BSEC BSEC output data
   @param[in] bsec      : Instance of BSEC2 calling the callback
*/
void newDataCallback(const bme68xData data, const bsecOutputs outputs, Bsec2 bsec);

/* Create an object of the class Bsec2 */
Bsec2 envSensor;

/**
   @brief      Arduino setup function
*/
void setup()
{
  // put your setup code here, to run once:
  Serial.begin(115200);
  /* Desired subscription list of BSEC2 outputs */
  bsecSensor sensorList[] = {
    BSEC_OUTPUT_IAQ,
    BSEC_OUTPUT_RAW_TEMPERATURE,
    BSEC_OUTPUT_RAW_PRESSURE,
    BSEC_OUTPUT_RAW_HUMIDITY,
    BSEC_OUTPUT_RAW_GAS,
    BSEC_OUTPUT_STABILIZATION_STATUS,
    BSEC_OUTPUT_RUN_IN_STATUS
  };
  current_time = millis();
  // comment out the below line to cancel the wait for USB connection (needed for native USB)
  while (!Serial) {
    if ((millis() - current_time) > 5000) {
      break;
    }
  }
  notecard.setDebugOutputStream(Serial);
  Serial.println("Edge Impulse Inferencing Demo");
  Wire.setSDA(0);
  Wire.setSCL(1);
  Wire.begin();
  notecard.begin();
  pinMode(PANIC_LED, OUTPUT);
  pinMode(LED_BUILTIN, OUTPUT);
  pinMode(22, OUTPUT);
  pinMode(23, OUTPUT);
  pinMode(24, OUTPUT);

  digitalWrite(LED_BUILTIN, HIGH);
  digitalWrite(22, HIGH);
  digitalWrite(23, HIGH);
  digitalWrite(24, HIGH);

  stepper.setSpeed(60);
  stepper.step(630);
  stepper.step(-315);
  delay(5000);

  /* Initialize the library and interfaces */
  if (!envSensor.begin(BME68X_I2C_ADDR_LOW, Wire))
  {
    checkBsecStatus(envSensor);
  }

  /* Subsribe to the desired BSEC2 outputs */
  if (!envSensor.updateSubscription(sensorList, ARRAY_LEN(sensorList), BSEC_SAMPLE_RATE_ULP))
  {
    checkBsecStatus(envSensor);
  }

  /* Whenever new data is available call the newDataCallback function */
  envSensor.attachCallback(newDataCallback);

  Serial.println("BSEC library version " + \
                 String(envSensor.version.major) + "." \
                 + String(envSensor.version.minor) + "." \
                 + String(envSensor.version.major_bugfix) + "." \
                 + String(envSensor.version.minor_bugfix));


  // summary of inferencing settings (from model_metadata.h)
  ei_printf("Inferencing settings:\n");
  ei_printf("\tInterval: ");
  ei_printf_float((float)EI_CLASSIFIER_INTERVAL_MS);
  ei_printf(" ms.\n");
  ei_printf("\tFrame size: %d\n", EI_CLASSIFIER_DSP_INPUT_FRAME_SIZE);
  ei_printf("\tSample length: %d ms.\n", EI_CLASSIFIER_RAW_SAMPLE_COUNT / 16);
  ei_printf("\tNo. of classes: %d\n", sizeof(ei_classifier_inferencing_categories) / sizeof(ei_classifier_inferencing_categories[0]));

  if (microphone_inference_start(EI_CLASSIFIER_RAW_SAMPLE_COUNT) == false) {
    ei_printf("ERR: Could not allocate audio buffer (size %d), this could be due to the window length of your model\r\n", EI_CLASSIFIER_RAW_SAMPLE_COUNT);
    return;
  }

  J *req = notecard.newRequest("hub.set");
  JAddStringToObject(req, "product", productUID);
  JAddStringToObject(req, "mode", "continuous");
  notecard.sendRequest(req);

  randomSeed(analogRead(0));


}

/**
   @brief      Arduino main function. Runs the inferencing loop.
*/
int consecutive_count = 0;
void loop()
{


  delay(30000);

  ei_printf("Recording...\n");

  bool m = microphone_inference_record();
  if (!m) {
    ei_printf("ERR: Failed to record audio...\n");
    return;
  }

  ei_printf("Recording done\n");

  signal_t signal;
  signal.total_length = EI_CLASSIFIER_RAW_SAMPLE_COUNT;
  signal.get_data = &microphone_audio_signal_get_data;
  ei_impulse_result_t result = { 0 };

  EI_IMPULSE_ERROR r = run_classifier(&signal, &result, debug_nn);
  if (r != EI_IMPULSE_OK) {
    ei_printf("ERR: Failed to run classifier (%d)\n", r);
    return;
  }

  // print inference return code
  ei_printf("run_classifier returned: %d\r\n", r);
  for (uint16_t i = 0; i < EI_CLASSIFIER_LABEL_COUNT; i++) {

    if (result.classification[i].value > 0.9) {
      ei_printf("Sound Detected: %s", ei_classifier_inferencing_categories[i]);
      consecutive_count++;
      if (!envSensor.run())
      {
        checkBsecStatus(envSensor);
      }
      if (consecutive_count >= 3) {
        consecutive_count = 0;
        int steps = 0;
        switch (i) {
          case 0:
            steps = 65;
            break;
          case 1:
            steps = 252;
            break;
          case 2:
            steps = 165;
            break;
        }

        stepper.step(-steps);
        delay(5000);
        stepper.step(steps);

      }
    }
  }

  J *req = notecard.newRequest("note.add");
  if (req != NULL) {
    JAddStringToObject(req, "file", "sensors.qo");
    JAddBoolToObject(req, "sync", true);

    J *body = JCreateObject();
    if (body != NULL) {
      JAddStringToObject(body, "source", "coffee");
      JAddNumberToObject(body, "iaq", random(50));
      JAddItemToObject(req, "body", body);
    }

    notecard.sendRequest(req);
  }

}

/**
   @brief      PDM buffer full callback
               Copy audio data to app buffers
*/
static void pdm_data_ready_inference_callback(void)
{
  int bytesAvailable = PDM.available();

  // read into the sample buffer
  int bytesRead = PDM.read((char *)&sampleBuffer[0], bytesAvailable);

  if ((inference.buf_ready == 0) && (record_ready == true)) {

    for (int i = 0; i < bytesRead >> 1; i++) {
      inference.buffer[inference.buf_count++] = sampleBuffer[i];

      if (inference.buf_count >= inference.n_samples) {
        inference.buf_count = 0;
        inference.buf_ready = 1;
        break;
      }
    }
  }
}

/**
   @brief      Init inferencing struct and setup/start PDM

   @param[in]  n_samples  The n samples

   @return     { description_of_the_return_value }
*/
static bool microphone_inference_start(uint32_t n_samples)
{
  inference.buffer = (int16_t *)malloc(n_samples * sizeof(int16_t));

  if (inference.buffer == NULL) {
    return false;
  }

  inference.buf_count  = 0;
  inference.n_samples  = n_samples;
  inference.buf_ready  = 0;

  // configure the data receive callback
  PDM.onReceive(pdm_data_ready_inference_callback);

  PDM.setBufferSize(2048);
  delay(250);

  // initialize PDM with:
  // - one channel (mono mode)
  if (!PDM.begin(1, EI_CLASSIFIER_FREQUENCY)) {
    ei_printf("ERR: Failed to start PDM!");
    microphone_inference_end();
    return false;
  }

  // optionally set the gain, defaults to 24
  // Note: values >=52 not supported
  //PDM.setGain(40);

  return true;
}

/**
   @brief      Wait on new data

   @return     True when finished
*/
static bool microphone_inference_record(void)
{
  bool ret = true;

  record_ready = true;
  while (inference.buf_ready == 0) {
    delay(10);
  }

  inference.buf_ready = 0;
  record_ready = false;

  return ret;
}

/**
   Get raw audio signal data
*/
static int microphone_audio_signal_get_data(size_t offset, size_t length, float *out_ptr)
{
  numpy::int16_to_float(&inference.buffer[offset], out_ptr, length);

  return 0;
}

/**
   @brief      Stop PDM and release buffers
*/
static void microphone_inference_end(void)
{
  PDM.end();
  ei_free(inference.buffer);
}

void print_inference_result(ei_impulse_result_t result) {

  // Print how long it took to perform inference

  for (uint16_t i = 0; i < EI_CLASSIFIER_LABEL_COUNT; i++) {

    if (result.classification[i].value > 0.9) {
      ei_printf("Sound Detected: %s", ei_classifier_inferencing_categories[i]);
    }
  }

  // Print anomaly result (if it exists)
#if EI_CLASSIFIER_HAS_ANOMALY == 1
  ei_printf("Anomaly prediction: %.3f\r\n", result.anomaly);
#endif

}

#if !defined(EI_CLASSIFIER_SENSOR) || EI_CLASSIFIER_SENSOR != EI_CLASSIFIER_SENSOR_MICROPHONE
#error "Invalid model for current sensor."
#endif

void errLeds(void)
{
  while (1)
  {
    digitalWrite(PANIC_LED, HIGH);
    delay(ERROR_DUR);
    digitalWrite(PANIC_LED, LOW);
    delay(ERROR_DUR);
  }
}

void newDataCallback(const bme68xData data, const bsecOutputs outputs, Bsec2 bsec)
{
  if (!outputs.nOutputs)
  {
    return;
  }

  Serial.println("BSEC outputs:\n\ttimestamp = " + String((int) (outputs.output[0].time_stamp / INT64_C(1000000))));
  for (uint8_t i = 0; i < outputs.nOutputs; i++)
  {
    const bsecData output  = outputs.output[i];
    switch (output.sensor_id)
    {
      case BSEC_OUTPUT_IAQ:
        Serial.println("\tiaq = " + String(output.signal));
        Serial.println("\tiaq accuracy = " + String((int) output.accuracy));
        break;
      case BSEC_OUTPUT_RAW_TEMPERATURE:
        Serial.println("\ttemperature = " + String(output.signal));
        break;
      case BSEC_OUTPUT_RAW_PRESSURE:
        Serial.println("\tpressure = " + String(output.signal));
        break;
      case BSEC_OUTPUT_RAW_HUMIDITY:
        Serial.println("\thumidity = " + String(output.signal));
        break;
      case BSEC_OUTPUT_RAW_GAS:
        Serial.println("\tgas resistance = " + String(output.signal));
        break;
      case BSEC_OUTPUT_STABILIZATION_STATUS:
        Serial.println("\tstabilization status = " + String(output.signal));
        break;
      case BSEC_OUTPUT_RUN_IN_STATUS:
        Serial.println("\trun in status = " + String(output.signal));
        break;
      default:
        break;
    }
  }
}

void checkBsecStatus(Bsec2 bsec)
{
  if (bsec.status < BSEC_OK)
  {
    Serial.println("BSEC error code : " + String(bsec.status));
    errLeds(); /* Halt in case of failure */
  }
  else if (bsec.status > BSEC_OK)
  {
    Serial.println("BSEC warning code : " + String(bsec.status));
  }

  if (bsec.sensor.status < BME68X_OK)
  {
    Serial.println("BME68X error code : " + String(bsec.sensor.status));
    errLeds(); /* Halt in case of failure */
  }
  else if (bsec.sensor.status > BME68X_OK)
  {
    Serial.println("BME68X warning code : " + String(bsec.sensor.status));
  }
}

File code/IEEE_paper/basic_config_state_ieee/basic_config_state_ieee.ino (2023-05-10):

/**
 * Copyright (C) 2021 Bosch Sensortec GmbH
 *
 * SPDX-License-Identifier: BSD-3-Clause
 * 
 */

/* If compiling this examples leads to an 'undefined reference error', refer to the README
 * at https://github.com/BoschSensortec/Bosch-BSEC2-Library
 */
/* The new sensor needs to be conditioned before the example can work reliably. You may run this
 * example for 24hrs to let the sensor stabilize.
 */

/**
 * basic_config_state.ino sketch :
 * This is an example for integration of BSEC2x library using configuration setting and has been 
 * tested with Adafruit ESP8266 Board
 * 
 * For quick integration test, example code can be used with configuration file under folder
 * Bosch_BSEC2_Library/src/config/FieldAir_HandSanitizer (Configuration file added as simple
 * code example for integration but not optimized on classification performance)
 * Config string for H2S and NonH2S target classes is also kept for reference (Suitable for
 * lab-based characterization of the sensor)
 */

/* Use the Espressif EEPROM library. Skip otherwise */
#if defined(ARDUINO_ARCH_ESP32) || (ARDUINO_ARCH_ESP8266)
#include <EEPROM.h>
#define USE_EEPROM
#endif

#include <bsec2.h>
/* Configuration for two class classification used here
 * For four class classification please use configuration under config/FieldAir_HandSanitizer_Onion_Cinnamon
 */
#include "config/coffee/coffee.h"

/* Macros used */
#define STATE_SAVE_PERIOD UINT32_C(360 * 60 * 1000) /* 360 minutes - 4 times a day */
#define PANIC_LED LED_BUILTIN
#define ERROR_DUR 1000
#define B 22
#define R 23
#define G 24
/* Helper functions declarations */
/**
 * @brief : This function toggles the led continuously with one second delay
 */
void errLeds(void);

/**
 * @brief : This function checks the BSEC status, prints the respective error code. Halts in case of error
 * @param[in] bsec  : Bsec2 class object
 */
void checkBsecStatus(Bsec2 bsec);

/**
 * @brief : This function updates/saves BSEC state
 * @param[in] bsec  : Bsec2 class object
 */
void updateBsecState(Bsec2 bsec);

/**
 * @brief : This function is called by the BSEC library when a new output is available
 * @param[in] input     : BME68X sensor data before processing
 * @param[in] outputs   : Processed BSEC BSEC output data
 * @param[in] bsec      : Instance of BSEC2 calling the callback
 */
void newDataCallback(const bme68xData data, const bsecOutputs outputs, Bsec2 bsec);

/**
 * @brief : This function retrieves the existing state
 * @param : Bsec2 class object
 */
bool loadState(Bsec2 bsec);

/**
 * @brief : This function writes the state into EEPROM
 * @param : Bsec2 class object
 */
bool saveState(Bsec2 bsec);

/* Create an object of the class Bsec2 */
Bsec2 envSensor;
#ifdef USE_EEPROM
static uint8_t bsecState[BSEC_MAX_STATE_BLOB_SIZE];
#endif
/* Gas estimate names will be according to the configuration classes used */
const String gasName[] = { "Normal", "Coffee", "Sharpie", "Undefined 4"};

void setup1(void){
    pinMode(R, OUTPUT);
    pinMode(G, OUTPUT);
    pinMode(B, OUTPUT);

    digitalWrite(R, HIGH);
    digitalWrite(G, HIGH);
    digitalWrite(B, HIGH);
}

void loop1(){
  digitalWrite(G, HIGH);
  delay(100);
  digitalWrite(G, LOW);
  delay(100);
}

/* Entry point for the example */
void setup(void)
{
  /* Desired subscription list of BSEC2 outputs */
    bsecSensor sensorList[] = {            
            BSEC_OUTPUT_RAW_GAS,
            BSEC_OUTPUT_RAW_GAS_INDEX, 
            BSEC_OUTPUT_GAS_ESTIMATE_1,
            BSEC_OUTPUT_GAS_ESTIMATE_2,
            BSEC_OUTPUT_GAS_ESTIMATE_3,
            BSEC_OUTPUT_GAS_ESTIMATE_4
    };

    Serial.begin(115200);
  #ifdef USE_EEPROM
    EEPROM.begin(BSEC_MAX_STATE_BLOB_SIZE + 1);
  #endif
    Wire.setSDA(0);
    Wire.setSCL(1);
    Wire.begin();
    pinMode(PANIC_LED, OUTPUT);
    
    
    digitalWrite(PANIC_LED, HIGH);
    
   
    /* Initialize the library and interfaces */
    if (!envSensor.begin(BME68X_I2C_ADDR_LOW, Wire))
    {
        checkBsecStatus(envSensor);
    }

    /* Load the configuration string that stores information on how to classify the detected gas */
    if (!envSensor.setConfig(coffee_config))
    {
        checkBsecStatus (envSensor);
    }

    /* Copy state from the EEPROM to the algorithm */
    if (!loadState(envSensor))
    {
        checkBsecStatus (envSensor);
    }

    /* Subscribe for the desired BSEC2 outputs */
    if (!envSensor.updateSubscription(sensorList, ARRAY_LEN(sensorList), BSEC_SAMPLE_RATE_SCAN))
    {
        checkBsecStatus (envSensor);
    }

    /* Whenever new data is available call the newDataCallback function */
    envSensor.attachCallback(newDataCallback);

    Serial.println("\nBSEC library version " + \
            String(envSensor.version.major) + "." \
            + String(envSensor.version.minor) + "." \
            + String(envSensor.version.major_bugfix) + "." \
            + String(envSensor.version.minor_bugfix));
}

/* Function that is looped forever */
void loop(void)
{
    /* Call the run function often so that the library can
     * check if it is time to read new data from the sensor
     * and process it.
     */
    if (!envSensor.run()) {
        checkBsecStatus (envSensor);
    }
}

void errLeds(void)
{
    while(1)
    {
        digitalWrite(PANIC_LED, HIGH);
        delay(ERROR_DUR);
        digitalWrite(PANIC_LED, LOW);
        delay(ERROR_DUR);
    }
}

void updateBsecState(Bsec2 bsec)
{
    static uint16_t stateUpdateCounter = 0;
    bool update = false;

    if (!stateUpdateCounter || (stateUpdateCounter * STATE_SAVE_PERIOD) < millis())
    {
        /* Update every STATE_SAVE_PERIOD minutes */
        update = true;
        stateUpdateCounter++;
    }

    if (update && !saveState(bsec))
        checkBsecStatus(bsec);
}
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

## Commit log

2023-01-24 Design files
    [badge.brd, badge.csv, badge.sch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]
2023-01-26 Arduino code check-in
2023-01-27 file re-org
    [badge.brd, badge.csv, badge.sch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]
2023-01-31 Checking master BoM
    [Master_BoM.xlsx]
2023-04-07 hardware changes
    [badge.brd, badge.sch, badge_top_bom.csv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]
2023-05-10 ieee paper
    [badge_top_bom.xlsx]

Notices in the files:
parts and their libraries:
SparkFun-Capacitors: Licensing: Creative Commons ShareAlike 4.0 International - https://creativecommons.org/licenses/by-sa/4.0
